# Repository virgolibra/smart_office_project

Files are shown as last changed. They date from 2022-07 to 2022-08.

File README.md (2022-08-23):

# smart_office_project

This is the repo for MSc CE dissertation.

### Introduce

The project introduces a method to build a seat occupancy system with a smart IoT office system. It contains three subsystems, which are smart chair system, smart desk occupancy system and smart desktop clock system, to provide desk occupancy monitoring, chair occupancy monitoring, desk check-in and out, and office indoor environmental parameter measurement. A Flutter App is designed for user interaction and data visualisation. 3D print PLA enclosure are used for sensor boxes. The system can be deployed in the office or study space.

------

### Hardware Requirements

+ Seat pressure sensors and Zigbee binary sensors.
+ Infrared motion sensor with ESP8266 NodeMCU module.
+ Integrated desktop clock with Arduino Nano 33 IoT.

##### Components List

+ Hub and Gateway

  + Raspberry Pi
  + ConBee II ZigBee Gateway

+ Chair sensor

  + Aqara water leak sensor

  + Seat pressure sensor

  + CR2032 Lithium Battery

+ Smart Desktop Clock

  + Arduino Nano 33 IoT
  + NeoPixel Stick
  + RC522 RFID module
  + BMP180 Sensor
  + TM1637 4-digits Display

+ Smart Desk Occupancy System

  + Lithium polymer ion battery
  + ESP8266 NodeMCU
  + HC-SR312 PIR motion sensor

+ Circuit board components

  + Stripboards
  + Solid wires
  + Connectors

+ Enclosures

  + 3D printed boxes and connectors
  + Cushion 

----------

### Software requirements

#### Home Assistant Installation

**Prerequisites:** 

1. Raspberry Pi 4
2. Power supply
3. SD card reader
4. Micro SD card

**Boot media:**

1. Attach SD card to computer as the boot media.
2. Download flasher software. ([Balena Etcher](https://www.balena.io/etcher/))
3. Flash from URL ```https://github.com/home-assistant/operating-system/releases/download/8.4/haos_rpi4-64-8.4.img.xz``` for Raspberry Pi 4 64-bit.
4. Download image, select SD card and flash.

**Setup Wi-Fi:**

1. Place the flashed SD card to a Windows PC.

2. Open it with file explorer.

3. Create a new folder named "CONFIG".

4. Open the folder and create another folder named "network"

5. Open the "network" folder create a plain text file named "my-network".

6. Edit it as follows. The [online UUID generator](https://www.uuidgenerator.net/version1)

   ```properties
   [connection]
   id=my-network
   uuid=72111c67-4a5d-4d5c-925e-f8ee26efb3c3
   type=802-11-wireless
   
   [802-11-wireless]
   mode=infrastructure
   ssid=MY_SSID
   # Uncomment below if your SSID is not broadcasted
   #hidden=true
   
   [802-11-wireless-security]
   auth-alg=open
   key-mgmt=wpa-psk
   psk=MY_WLAN_SECRET_KEY
   
   [ipv4]
   method=auto
   
   [ipv6]
   addr-gen-mode=stable-privacy
   method=auto
   ```

7. Save the changes, remove the SD card and plug into Raspberry Pi.
8. Boot Raspberry Pi, the specified network should be connected.

**Config Home Assistant**

1. After network connection, Home Assistant can be accessed in the browser of the Desktop system on `homeassistant.local:8123`, or `homeassistant:8123`, or `http://[IPAddress]:8123`in a few minutes.
2. Follow the instructions in [Home Assistant official guideline](https://www.home-assistant.io/getting-started/onboarding/).

#### Flutter Mobile App

**Prerequisites:** 

1. Any Operating System (Linux, Windows, MacOS etc.)
2. Any IDE with Flutter SDK installed (VSCode, Android Studio, XCode, etc.)
3. Basic knowledge and practice of Flutter and Dart.
4. Setup Firebase App based on [Firebase official guideline](https://firebase.google.com/docs/guides).

**Dependencies:**

```yaml
  cupertino_icons: ^1.0.2
  cloud_firestore: ^3.1.14
  firebase_auth: ^3.3.17
  firebase_core: ^1.12.0
  firebase_storage: ^10.2.16
  provider: ^6.0.2
  google_fonts: ^2.3.2
  bottom_bar: ^1.3.0+1
  geolocator: ^8.2.0
  weather: ^2.0.1
  mqtt_client: ^9.6.2
  camera: ^0.9.4+21
```

----

### Data Visualisation

#### Grafana with InfluxDB in Home Assistant

Home Assistant 

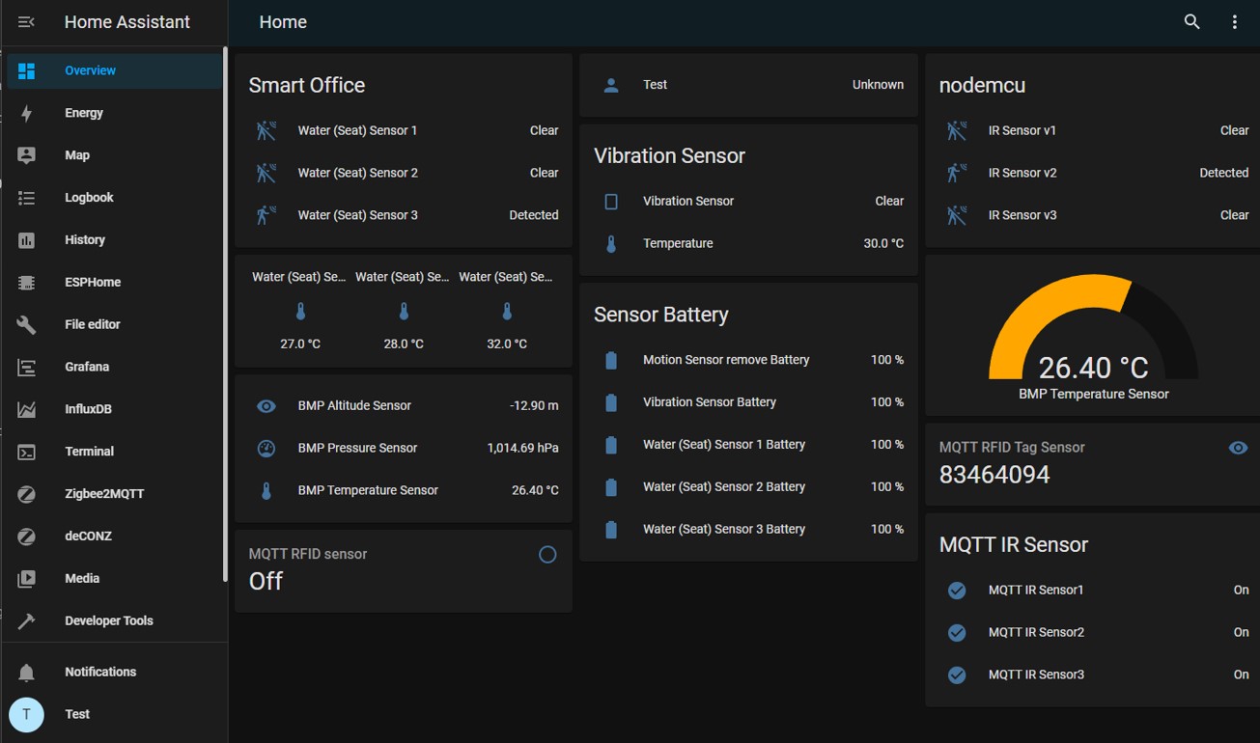
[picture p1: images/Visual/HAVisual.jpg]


Grafana

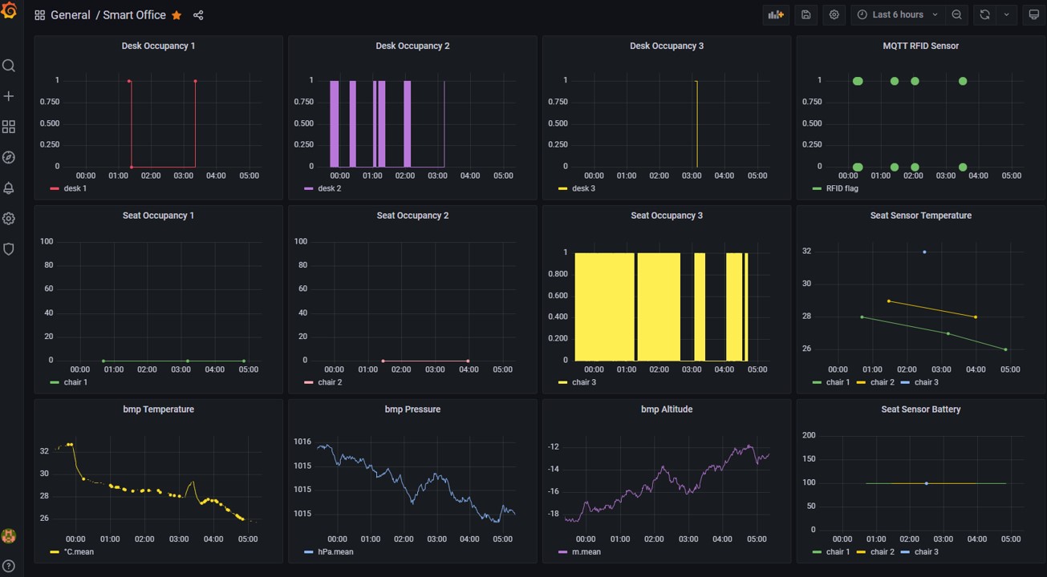
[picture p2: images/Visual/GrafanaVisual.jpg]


App

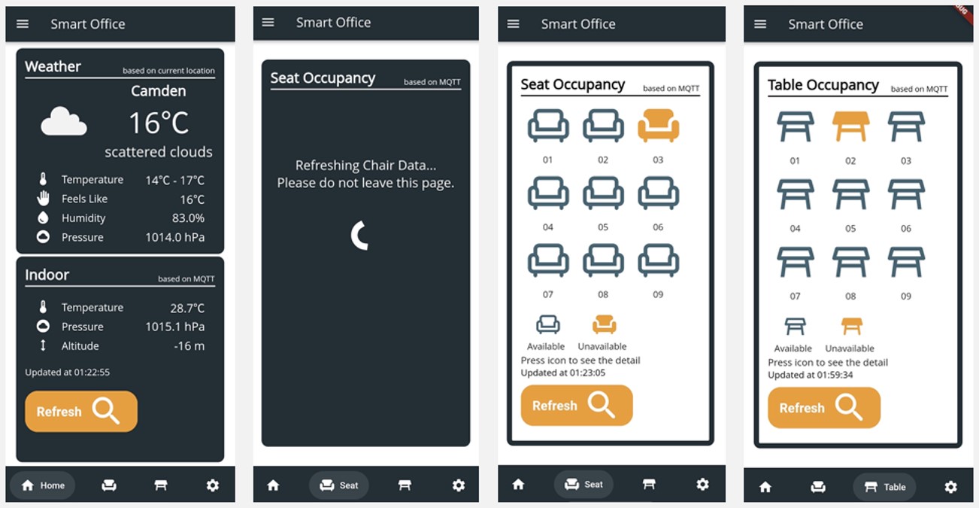
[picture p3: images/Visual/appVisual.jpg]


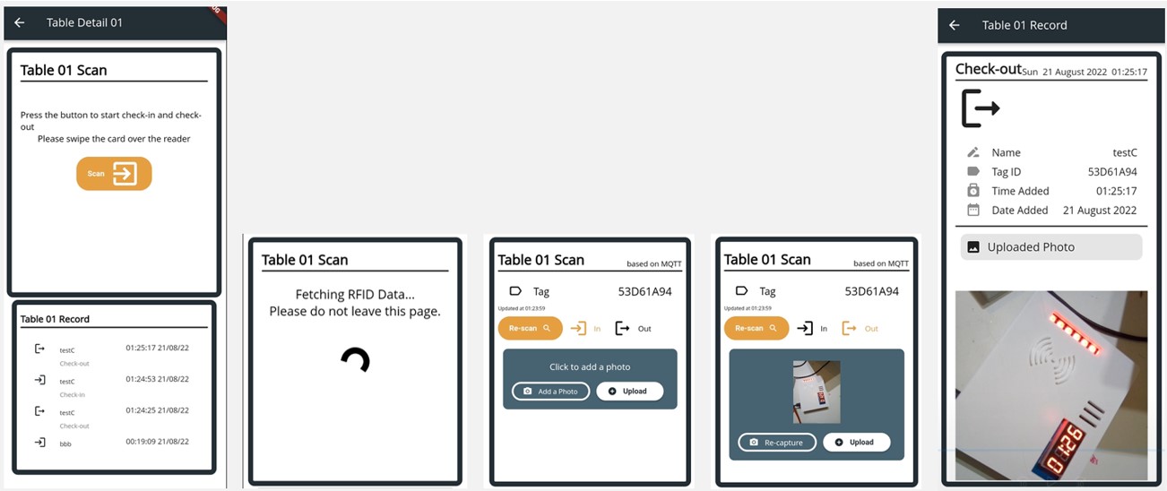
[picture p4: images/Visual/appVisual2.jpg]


----

### Application Demo YouTube Link

https://youtube.com/shorts/BBJ_iGN9C2Y?feature=share

-----

## Contact Details

If you have any questions, please feel free to contact me: [minghao.zhang.21@ucl.ac.uk](https://github.com/virgolibra/casa0015-mobile-assessment/blob/master/minghao.zhang.21@ucl.ac.uk)

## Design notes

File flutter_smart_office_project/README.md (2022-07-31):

# flutter_smart_office_project

A new Flutter application.

## Getting Started

This project is a starting point for a Flutter application.

A few resources to get you started if this is your first Flutter project:

- [Lab: Write your first Flutter app](https://flutter.dev/docs/get-started/codelab)
- [Cookbook: Useful Flutter samples](https://flutter.dev/docs/cookbook)

For help getting started with Flutter, view our
[online documentation](https://flutter.dev/docs), which offers tutorials,
samples, guidance on mobile development, and a full API reference.

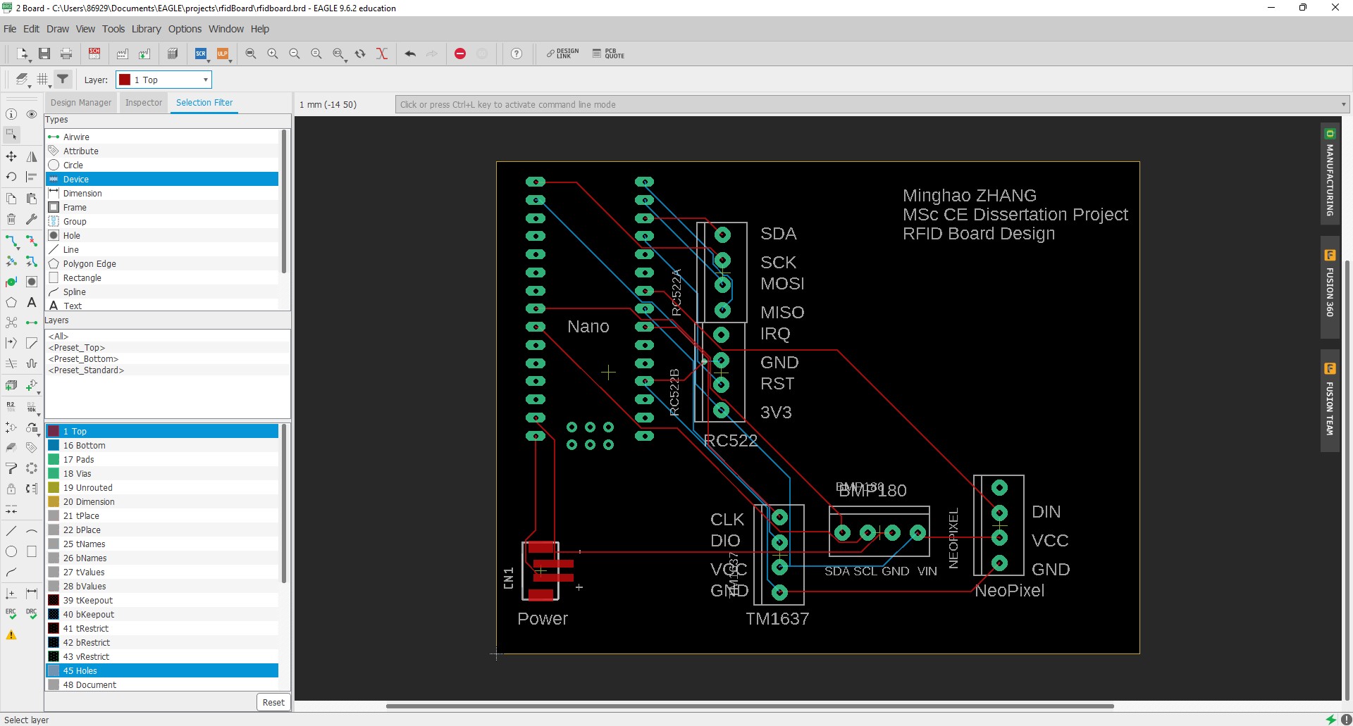
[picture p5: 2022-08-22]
images/PCBdesign/rfidBoardAllLayer.jpg

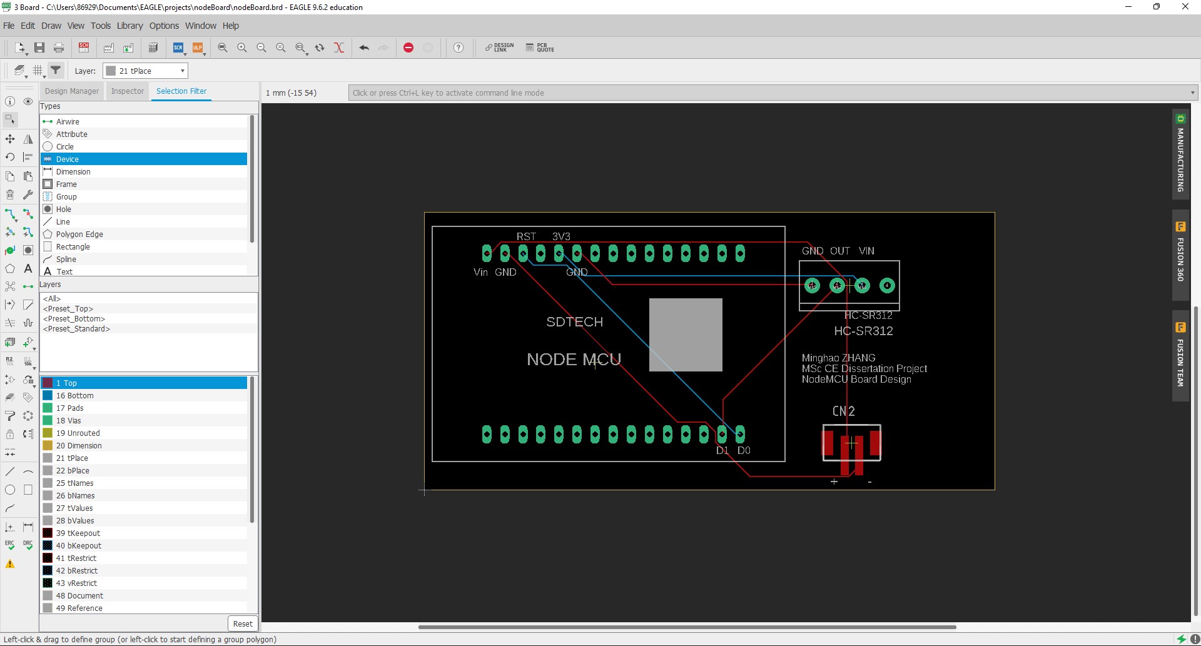
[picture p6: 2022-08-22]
images/PCBdesign/nodeBoardAllLayer.jpg

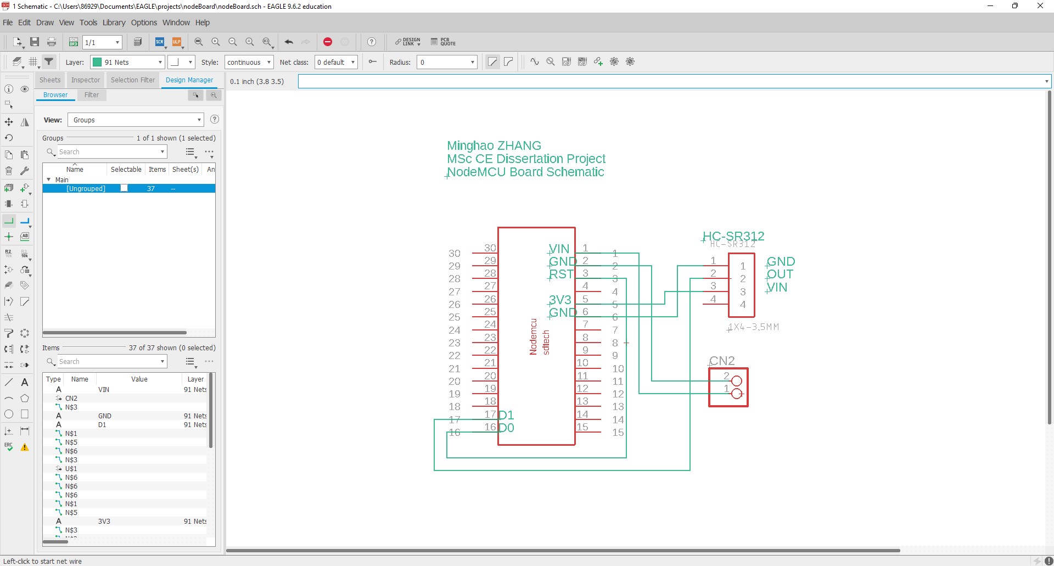
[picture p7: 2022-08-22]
images/PCBdesign/nodeBoardSchematic.jpg

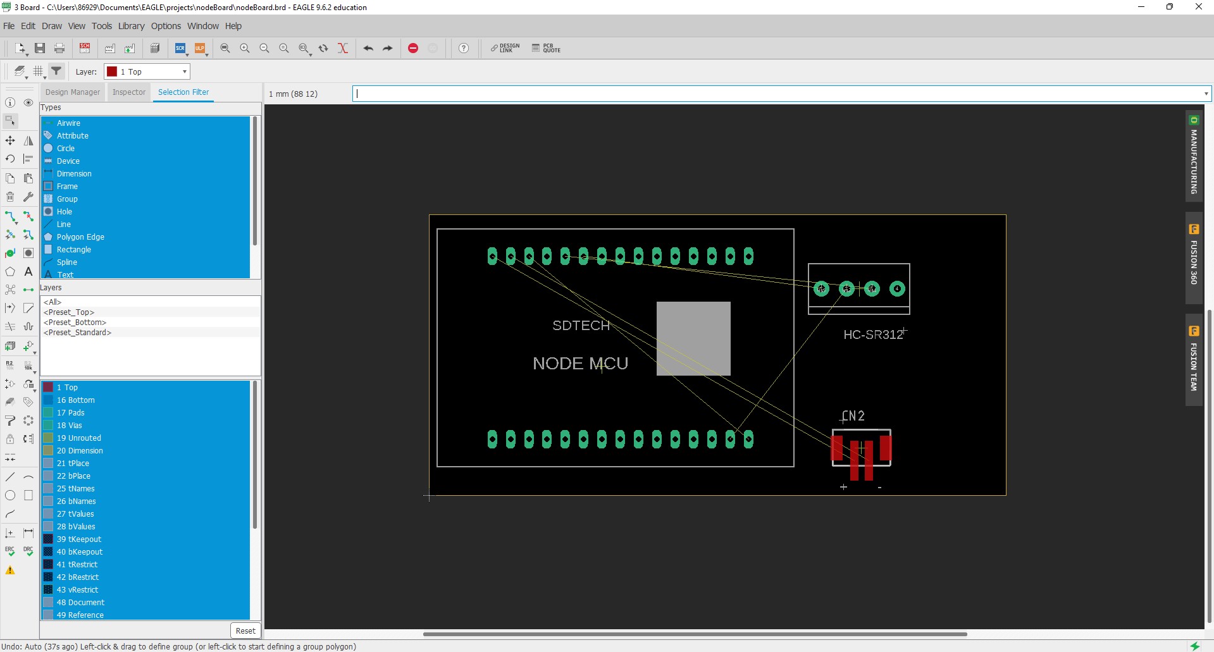
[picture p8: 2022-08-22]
images/PCBdesign/nodeBoardAirWire.jpg

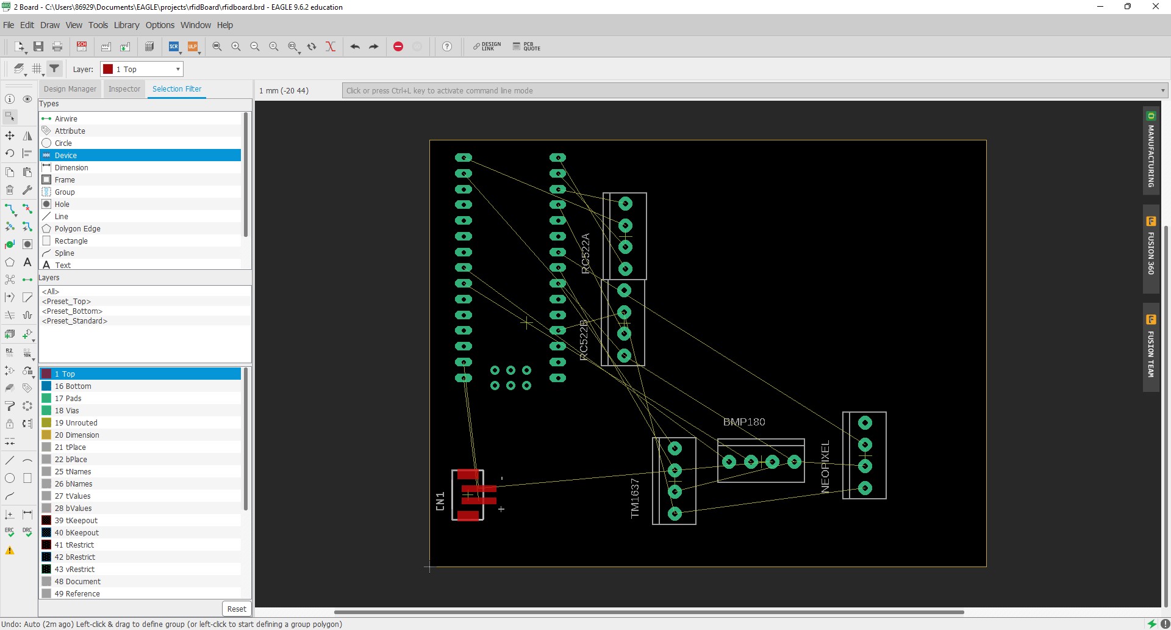
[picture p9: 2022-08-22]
images/PCBdesign/rfidBoardAirWire.jpg

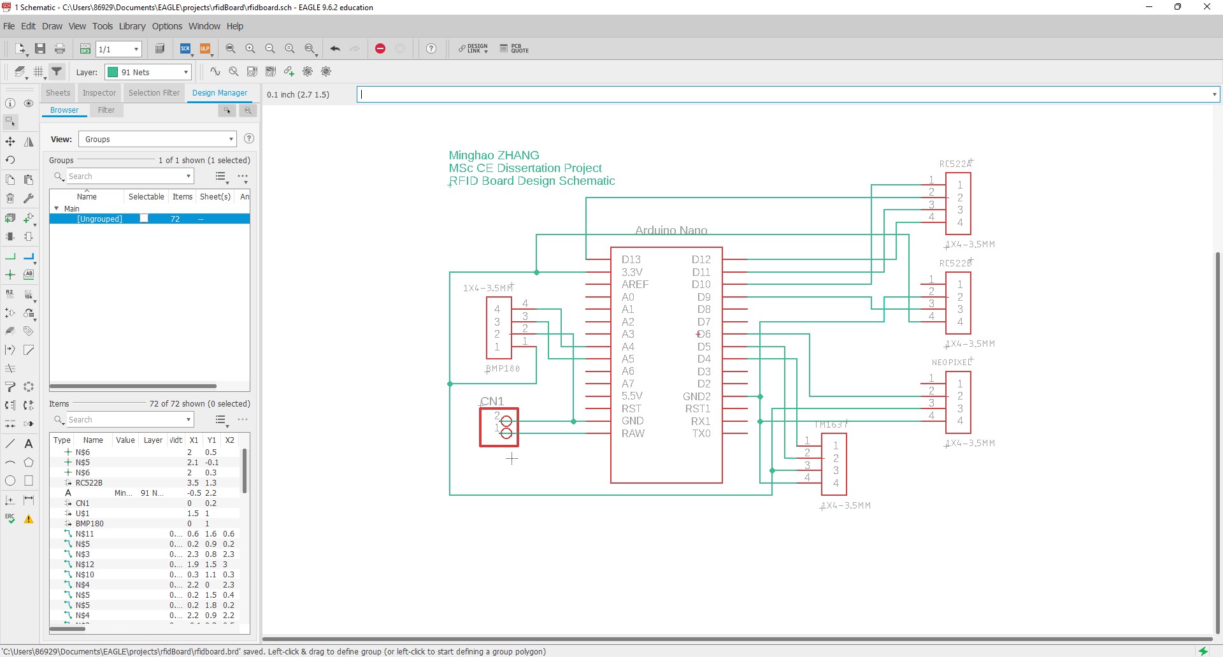
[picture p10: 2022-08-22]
images/PCBdesign/rfidBoardSchematic.jpg

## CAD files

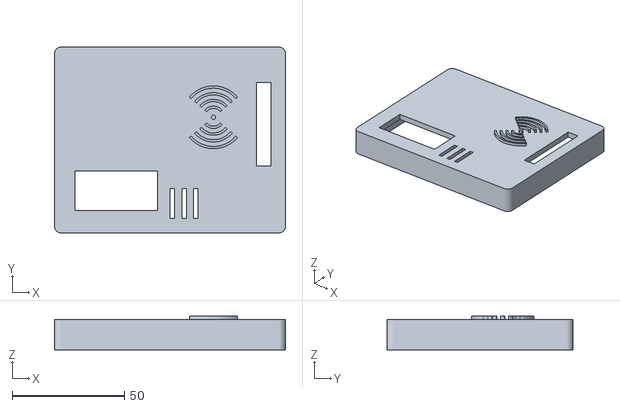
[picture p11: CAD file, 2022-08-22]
fusion3DModel/RFIDcoverAugustV1.stl
103.0 x 83.0 x 15.0

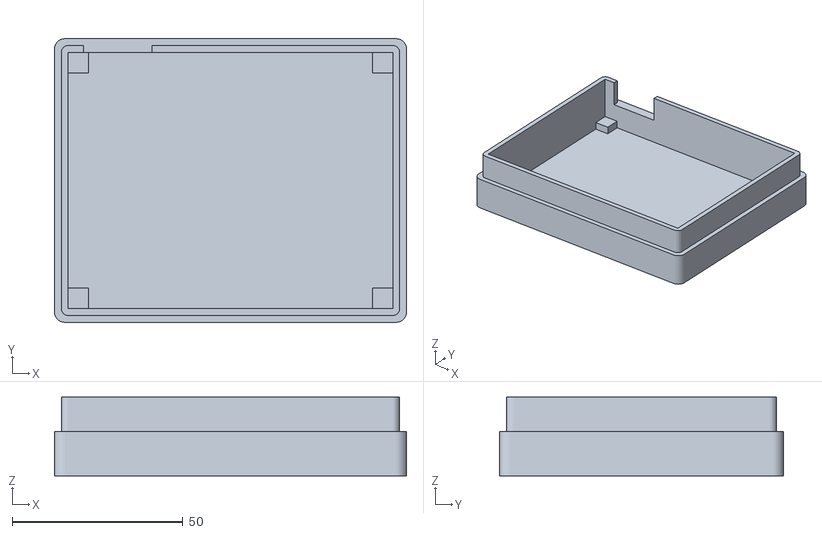
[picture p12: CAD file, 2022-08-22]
fusion3DModel/RFIDbaseAugustV1.stl
103.0 x 83.0 x 23.0

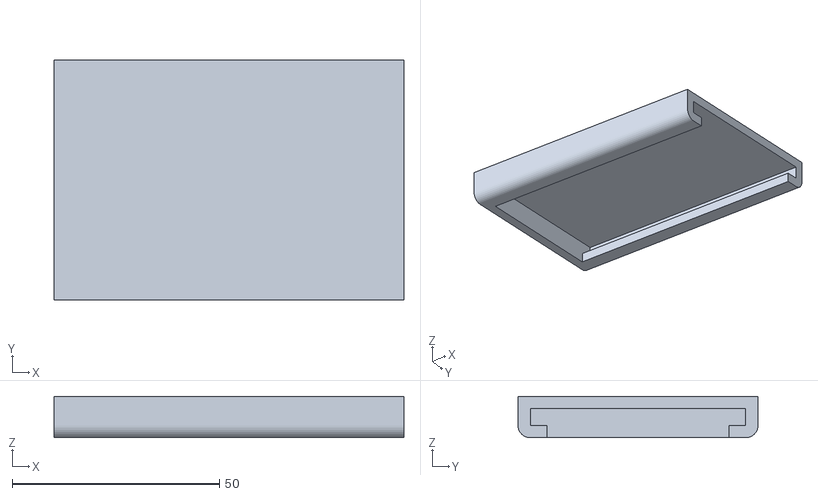
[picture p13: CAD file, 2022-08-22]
fusion3DModel/IRboxHolderAugustV1.stl
84.5 x 58.0 x 10.0

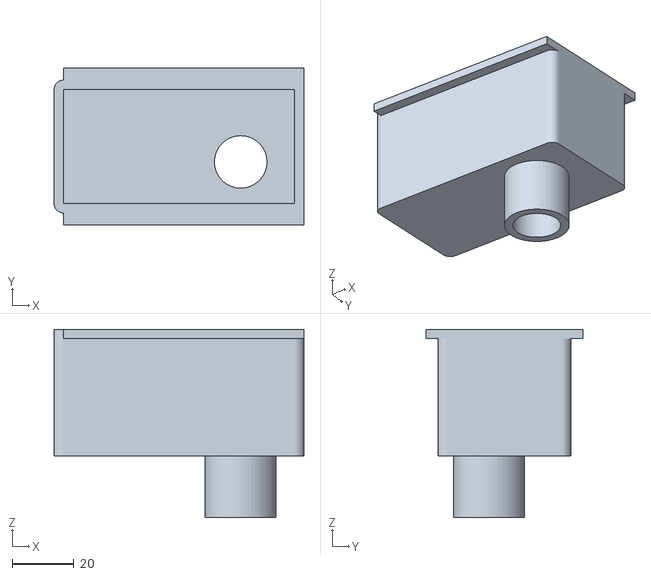
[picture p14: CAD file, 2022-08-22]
fusion3DModel/IRboxBaseAugustV1.stl
81.0 x 51.0 x 61.0

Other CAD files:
fusion3DModel/IRboxAugust v4.f3d
fusion3DModel/RFIDBox v2.f3d

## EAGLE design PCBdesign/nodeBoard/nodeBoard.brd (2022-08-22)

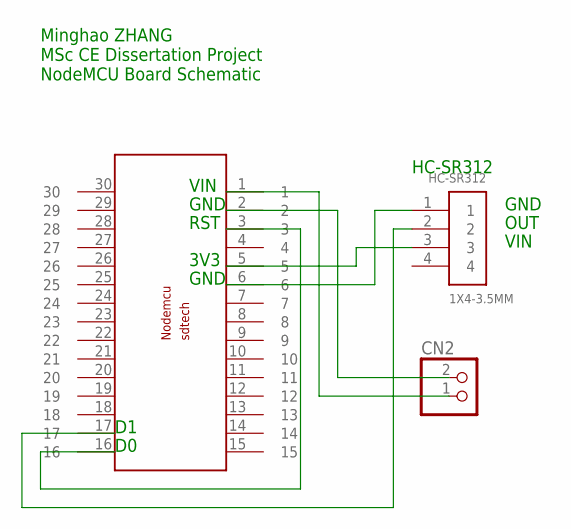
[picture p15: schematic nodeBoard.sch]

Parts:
CN2: JST_2PIN-SMT; JST-PH-2-SMT
HC-SR312: 1X4-3.5MM; 1X04-3.5MM
U$1: NODEMCUESP8266

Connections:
unnamed: CN2.1 (2), U$1.1
unnamed: CN2.2 (1), U$1.2
unnamed: HC-SR312.2, U$1.17
unnamed: HC-SR312.3, U$1.5
unnamed: HC-SR312.1, U$1.6
unnamed: U$1.3, U$1.16

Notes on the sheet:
Minghao ZHANG MSc CE Dissertation Project NodeMCU Board Schematic
HC-SR312
OUT
GND
VIN
RST
3V3

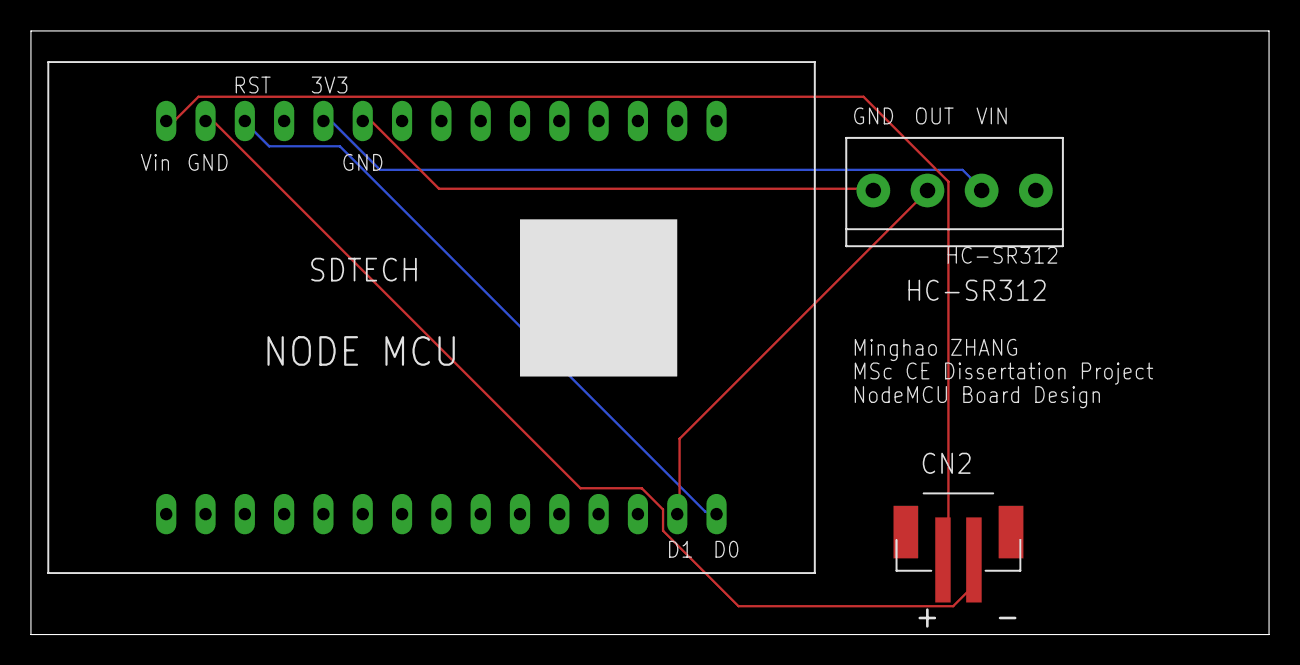
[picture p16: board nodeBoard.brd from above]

Board: 2 copper layers, 80.0 x 39.0 mm, 3 parts (0 on the bottom side), 6 nets.

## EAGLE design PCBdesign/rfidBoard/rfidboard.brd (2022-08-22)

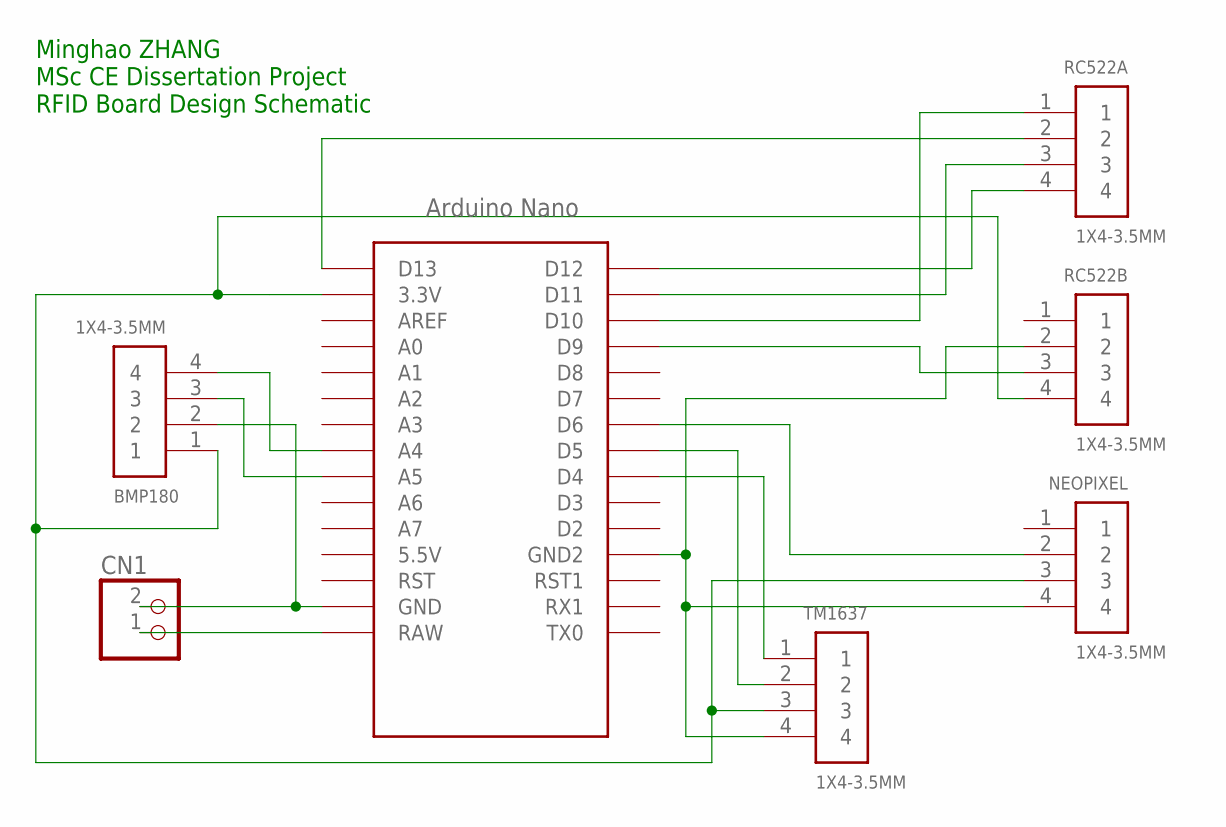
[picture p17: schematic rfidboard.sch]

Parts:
BMP180: 1X4-3.5MM; 1X04-3.5MM
CN1: JST_2PIN-SMT; JST-PH-2-SMT
NEOPIXEL: 1X4-3.5MM; 1X04-3.5MM
RC522A, RC522B: 1X4-3.5MM; 1X04-3.5MM
TM1637: 1X4-3.5MM; 1X04-3.5MM
U$1: NANO

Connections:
unnamed: CN1.1 (2), U$1.RAW
unnamed: BMP180.2, CN1.2 (1), U$1.GND
unnamed: TM1637.1, U$1.D4
unnamed: TM1637.2, U$1.D5
unnamed: BMP180.1, NEOPIXEL.3, RC522B.4, TM1637.3, U$1.3.3V
unnamed: NEOPIXEL.4, RC522B.2, TM1637.4, U$1.GND1 (GND2)
unnamed: NEOPIXEL.2, U$1.D6
unnamed: RC522A.1, U$1.D10
unnamed: BMP180.4, U$1.A4
unnamed: BMP180.3, U$1.A5
unnamed: RC522A.2, U$1.D13
unnamed: RC522A.3, U$1.D11
unnamed: RC522A.4, U$1.D12
unnamed: RC522B.3, U$1.D9

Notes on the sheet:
Minghao ZHANG MSc CE Dissertation Project RFID Board Design Schematic

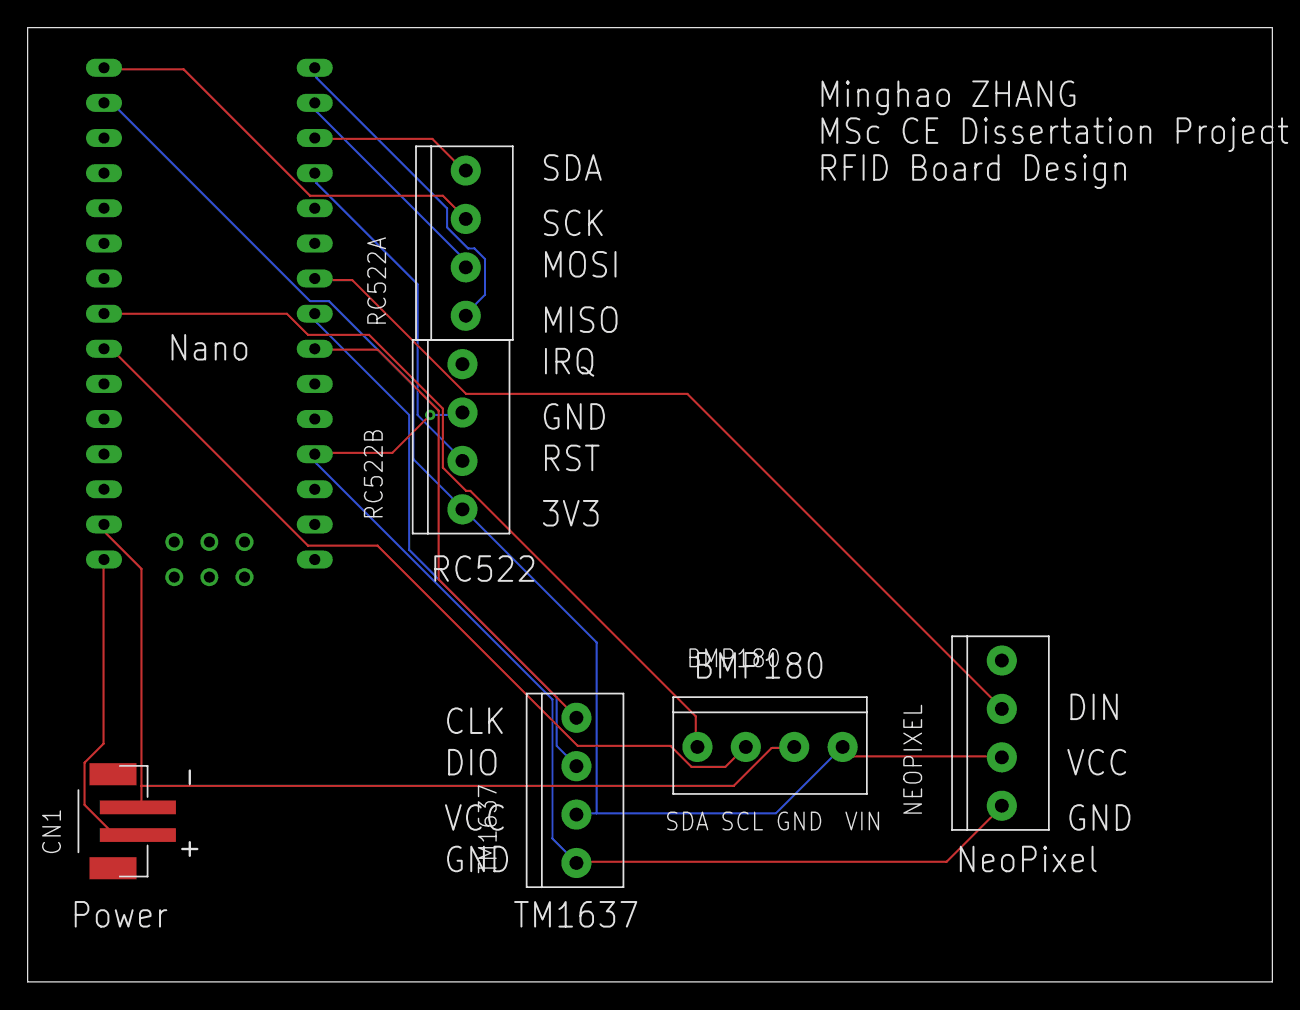
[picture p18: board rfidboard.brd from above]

Board: 2 copper layers, 90.0 x 69.0 mm, 7 parts (0 on the bottom side), 14 nets.

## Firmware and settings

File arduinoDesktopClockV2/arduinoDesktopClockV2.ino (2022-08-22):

#include <SPI.h>
#include <MFRC522.h>
#include <Adafruit_NeoPixel.h>
#include <TM1637.h>
#include <Wire.h>
#include <Adafruit_BMP085.h>
#include <ArduinoMqttClient.h>  // MQTT

#include <WiFiNINA.h>
#include <WiFiUdp.h>
#include <RTCZero.h>
#include "arduino_secrets.h"


#define RST_PIN 9
#define SS_PIN 10
#define pixelPin 6
#define TM_CLK 4
#define TM_DIO 5

#define NUMPIXELS 8
#define pixelBrightness 5
#define seaLevelPressure_hPa 1013.25  // Pressure at sea level

// ------------------ Wi-Fi and MQTT connection ----------------------------------------------------
char ssid[] = SECRET_SSID;        // your network SSID
char pass[] = SECRET_PASS;    // your network password
const char* mqttuser = SECRET_MQTTUSER;
const char* mqttpass = SECRET_MQTTPASS;

int keyIndex = 0;                 // your network key Index number (needed only for WEP)
int status = WL_IDLE_STATUS;      //connection status

WiFiClient wifiClient;
MqttClient mqttClient(wifiClient);


const char broker[] = "mqtt.cetools.org";
int        port     = 1884;
const char topic1_temperature[]  = "student/CASA0022/ucfnmz0/nano33/temperature";
const char topic2_tagID[]  = "student/CASA0022/ucfnmz0/nano33/tagID";
const char topic3_pressure[]  = "student/CASA0022/ucfnmz0/nano33/pressure";
const char topic4_altitude[]  = "student/CASA0022/ucfnmz0/nano33/altitude";
const char topic5_tagFlag[]  = "student/CASA0022/ucfnmz0/nano33/tagFlag";
//const char topic5_ppm[]  = "student/CASA0016/project/ucfnmz0/ppm";
//const char topic6_sound[]  = "student/CASA0016/project/ucfnmz0/soundStatus";
//const char topic7_uv[]  = "student/CASA0016/project/ucfnmz0/uvValue";

// -------------------------------------------

const int GMT = 1;
RTCZero rtc_wifi;

// Variable to represent epoch
unsigned long epoch;

// Variable for number of tries to NTP service
int numberOfTries = 0, maxTries = 5;

bool timeFlag = false;


byte set_year = 0; // can only be 2-digit year
byte set_month = 0;
byte set_date = 0;
byte set_hour = 0;
byte set_minute = 0;
byte set_second = 0;
void initRealTime() {
  set_year = rtc_wifi.getYear(); // can only be 2-digit year
  set_month = rtc_wifi.getMonth();
  set_date = rtc_wifi.getDay();
  set_hour = rtc_wifi.getHours();
  set_minute = rtc_wifi.getMinutes();
  set_second = rtc_wifi.getSeconds();
}

byte readCard[4];
//String MasterTag = "20C3935E";  // REPLACE this Tag ID with your Tag ID!!!
String MasterTag = "83464094";  // REPLACE this Tag ID with your Tag ID!!!
String tagID = "";

// Create instances
MFRC522 mfrc522(SS_PIN, RST_PIN);
Adafruit_NeoPixel pixels(NUMPIXELS, pixelPin);
TM1637 tm(TM_CLK, TM_DIO);
Adafruit_BMP085 bmp;

float bmpTemperature = 0;
float bmpPressure = 0; // pressure and altitude (BMP180)
float bmpAltitude = 0;
unsigned int tagFlag = 0;



void setup()
{
  // Initiating
  Serial.begin(9600);   // Initialize serial communications with the PC
//  while (!Serial);

  // ------------- WIFI & MQTT init --------------------


  // attempt to connect to Wifi network:
  Serial.print("Attempting to connect to SSID: ");
  Serial.println(ssid);

  setupPixelDisplay(2);
  while (WiFi.begin(ssid, pass) != WL_CONNECTED) {
    // failed, retry
    Serial.print(".");
    delay(5000);
  }

  Serial.println("You're connected to the network");
  Serial.println();

  setupPixelDisplay(3);
  delay(1000);

  Serial.print("Attempting to connect to the MQTT broker: ");
  Serial.println(broker);

  setupPixelDisplay(4);
  mqttClient.setUsernamePassword(mqttuser, mqttpass);
  if (!mqttClient.connect(broker, port)) {
    Serial.print("MQTT connection failed! Error code = ");
    Serial.println(mqttClient.connectError());

    while (1);
  }

  Serial.println("You're connected to the MQTT broker!");
  Serial.println();

  setupPixelDisplay(5);
  delay(1000);

  //----------------------------------


  SPI.begin(); // SPI bus
  mfrc522.PCD_Init(); // MFRC522
  pixels.begin();
  setScaningPixelDisplay();
  delay(200);


  Serial.println("Scan Your Card>>");
  displayNumber(0000);

  // BMP180 init and check if BMP180 exist
  if (!bmp.begin()) {
    Serial.println("Cannot find BMP180 Module");
    while (1) {}
  }


  // ------------- Time display --------------------
  tm.init();
  tm.set(2);  //set brightness; 0-7

  delay(1000);
  // Start Real Time Clock
  rtc_wifi.begin();


  do {
    epoch = WiFi.getTime();
    Serial.print(WiFi.getTime());
    numberOfTries++;
    Serial.print("tryGetTime");
    delay(200);
  }

  while ((epoch == 0) && (numberOfTries < maxTries));

  if (numberOfTries == maxTries) {
    Serial.print("NTP unreachable!!");
    while (1);
  }

  else {
    Serial.print("Epoch received: ");
    Serial.println(epoch);
    rtc_wifi.setEpoch(epoch + GMT * 60 * 60);
    Serial.println();
  }

  initRealTime();
  Serial.println("Initializing real time done.");
  Serial.println("Online date & time: " + String(set_year) + "-" + String(set_month) + "-" + String(set_date) + " " + String(set_hour) + ":" + String(set_minute) + ":" + String(set_second));



  // -------------- init sensor data update --------
  displayTime();
  getBmpData();
  sendMQTT();

  Serial.println();

  delay(1000);
}

void loop()
{


  mqttClient.poll();


  displayTime();
  getBmpData();
  getID();
  sendMQTT();

  if ((rtc_wifi.getSeconds() > 10) && (timeFlag == false) ) {
    if (getEpochFromWifi()) {
      Serial.println("Time calibration failed");
    } else {
      Serial.println("Time calibrated");
      timeDonePixelDisplay();

    }
    timeFlag = true;
    Serial.println("timeFlag == true");
  }

  if ((rtc_wifi.getSeconds() > 0) && (rtc_wifi.getSeconds() < 10) && (timeFlag == true)) {
    timeFlag = false;

    Serial.println("timeFlag == false");
  }
  delay(2000);


  //
  //  //Wait until new tag is available
  //  while (getID())
  //  {
  //
  //
  //    if (tagID == MasterTag)
  //    {
  //      setGrantedPixelDisplay();
  //      Serial.println(" Access Granted!");
  //      // You can write any code here like opening doors, switching on a relay, lighting up an LED, or anything else you can think of.
  //
  //
  //
  //    }
  //    else
  //    {
  //      setDeniedPixelDisplay();
  //
  //      Serial.println(" Access Denied!");
  //    }
  //
  //    Serial.print(" ID : ");
  //    Serial.println(tagID);
  //
  //    delay(2000);
  //
  //    setScaningPixelDisplay();
  //
  //    Serial.println(" Access Control ");
  //    Serial.println("Scan Your Card>>");
  //  }
}

//Read new tag if available
boolean getID()
{
  tagFlag = 0;
  // Getting ready for Reading PICCs
  if ( ! mfrc522.PICC_IsNewCardPresent()) { //If a new PICC placed to RFID reader continue
    return false;
  }
  if ( ! mfrc522.PICC_ReadCardSerial()) { //Since a PICC placed get Serial and continue
    return false;
  }
  tagID = "";
  for ( uint8_t i = 0; i < 4; i++) { // The MIFARE PICCs that we use have 4 byte UID
    //readCard[i] = mfrc522.uid.uidByte[i];
    tagID.concat(String(mfrc522.uid.uidByte[i], HEX)); // Adds the 4 bytes in a single String variable
  }
  tagID.toUpperCase();
  mfrc522.PICC_HaltA(); // Stop reading
  cardReadPixelDisplay();
  tagFlag = 1;
  return true;
}

void setDeniedPixelDisplay() {
  pixels.clear();
  for (int i = 0; i < NUMPIXELS; i++) {
    pixels.setPixelColor(i, 204, 102, 0); // orange
    pixels.setBrightness(pixelBrightness);
  }
  pixels.show();
}

void setGrantedPixelDisplay() {
  pixels.clear();
  for (int i = 0; i < NUMPIXELS; i++) {
    //    pixels.setPixelColor(i, 150, 0, 0); //red
    pixels.setPixelColor(i, 0, 155, 0); //green
    pixels.setBrightness(pixelBrightness);
  }

  pixels.show();
}

void setScaningPixelDisplay() {
  pixels.clear();
  for (int i = 0; i < NUMPIXELS; i++) {
    //    pixels.setPixelColor(i, 150, 0, 0); //red
    pixels.setPixelColor(i, 0, 0, 155); //blue
    pixels.setBrightness(pixelBrightness);
  }

  pixels.show();
}

void setupPixelDisplay(int numberOfPixelOn) {
  pixels.clear();
  for (int i = 0; i < numberOfPixelOn; i++) {
    pixels.setPixelColor(i, 150, 0, 0); // red
    pixels.setBrightness(pixelBrightness);
  }
  pixels.show();
}

void mqttUploadPixelDisplay() {
  //  for (int i = 0; i < NUMPIXELS; i++) {
  //    pixels.clear();
  //    pixels.setPixelColor(i, 0, 102, 204); // blue
  //    pixels.setBrightness(pixelBrightness);
  //    pixels.show();
  //    delay(50);
  //  }
  //
  //  pixels.clear();
  //  pixels.show();
  //  delay(100);
  //
  //  for (int i = 0; i < NUMPIXELS; i++) {
  //    pixels.setPixelColor(i, 0, 102, 204); // blue
  //    pixels.setBrightness(pixelBrightness);
  //  }
  //  pixels.show();

  pixels.clear();
  for (int i = 0; i < 8; i++) {
    pixels.setPixelColor(i, 150, 0, 0); // red
    pixels.setBrightness(pixelBrightness);
  }
  pixels.show();

}

void timeDonePixelDisplay() {
  for (int i = 0; i < NUMPIXELS; i++) {
    pixels.clear();
    pixels.setPixelColor(i, 153, 102, 204); // purple
    pixels.setBrightness(pixelBrightness);
    pixels.show();
    delay(50);
  }

  pixels.clear();
  pixels.show();
  delay(100);

  for (int i = 0; i < NUMPIXELS; i++) {
    pixels.setPixelColor(i, 153, 102, 204); // purple
    pixels.setBrightness(pixelBrightness);
  }
  pixels.show();



}


void cardReadPixelDisplay() {
  for (int i = 0; i < NUMPIXELS; i++) {
    pixels.clear();
    pixels.setPixelColor(i, 0, 140, 20); // green
    pixels.setBrightness(pixelBrightness);
    pixels.show();
    delay(50);
  }

  pixels.clear();
  pixels.show();
  delay(100);

  for (int i = 0; i < NUMPIXELS; i++) {
    pixels.setPixelColor(i, 0, 140, 20); // blue
    pixels.setBrightness(pixelBrightness);
  }
  pixels.show();

  delay(1000);


}

void displayNumber(int num) {
  tm.display(3, num % 10);
  tm.display(2, num / 10 % 10);
  tm.display(1, num / 100 % 10);
  tm.display(0, num / 1000 % 10);
}


void displayTime() {

  // display hour
  int numHour = rtc_wifi.getHours();
  tm.display(1, numHour % 10);
  tm.display(0, numHour / 10 % 10);

  // display minute
  int numMinute = rtc_wifi.getMinutes();
  tm.display(3, numMinute % 10);
  tm.display(2, numMinute / 10 % 10);

  tm.point(1);

}

void getBmpData() {
  bmpTemperature = bmp.readTemperature();
  bmpPressure = bmp.readSealevelPressure() * 0.01;
  bmpAltitude = bmp.readAltitude(seaLevelPressure_hPa * 100);

  Serial.print(">>> BMP Update |");
  Serial.print("Temperature: ");
  Serial.print(bmpTemperature);
  Serial.print(" *C");
  Serial.print(" | Pressure: ");
  Serial.print(bmpPressure);
  Serial.print(" hPa");
  Serial.print(" | Real altitude: ");
  Serial.print(bmpAltitude);
  Serial.println(" meters");

}
// ------------------------------------------------------------------------------------
//                                    send MQTT
// ------------------------------------------------------------------------------------
void sendMQTT() {



  // call poll() regularly to allow the library to send MQTT keep alive which
  // avoids being disconnected by the broker
  mqttClient.poll();

  if (mqttClient.connected()) {
    // send message, the Print interface can be used to set the message contents
    mqttClient.beginMessage(topic1_temperature);
    mqttClient.print(bmpTemperature);
    mqttClient.endMessage();

    mqttClient.beginMessage(topic2_tagID);
    mqttClient.print(tagID);
    mqttClient.endMessage();

    mqttClient.beginMessage(topic3_pressure);
    mqttClient.print(bmpPressure);
    mqttClient.endMessage();

    mqttClient.beginMessage(topic4_altitude);
    mqttClient.print(bmpAltitude);
    mqttClient.endMessage();

    mqttClient.beginMessage(topic5_tagFlag);
    mqttClient.print(tagFlag);
    mqttClient.endMessage();

    //    mqttClient.beginMessage(topic5_ppm);
    //    mqttClient.print(mqPPM);
    //    mqttClient.endMessage();
    //
    //    mqttClient.beginMessage(topic6_sound);
    //    mqttClient.print(soundDetectorStatus);
    //    mqttClient.endMessage();
    //
    //    mqttClient.beginMessage(topic7_uv);
    //    mqttClient.print(uvValue);
    //    mqttClient.endMessage();

    Serial.println("Sending messages to MQTT done!");
    Serial.println();

    mqttUploadPixelDisplay();
  }

  else { // if the client has been disconnected,
    Serial.println("Client disconnected, attempting reconnection");
    Serial.println();


    if (!attemptReconnect()) { // try reconnecting
      Serial.print("Client reconnected!");
      Serial.println();

    }

  }

}


int attemptReconnect() {
  if (!mqttClient.connect(broker, port)) {
    Serial.print("MQTT connection failed! Error code = ");
    Serial.println(mqttClient.connectError());

  }
  return mqttClient.connectError(); // return status
}


int getEpochFromWifi() {
  // Get epoch
  do {
    epoch = WiFi.getTime();
    Serial.print(WiFi.getTime());
    numberOfTries++;
    Serial.print("tryGetTime");
    delay(200);
  }

  while ((epoch == 0) && (numberOfTries < maxTries));

  if (numberOfTries == maxTries) {
    Serial.print("NTP unreachable!!");
    return 1;
  }

  else {
    Serial.print("Epoch received: ");
    Serial.println(epoch);
    rtc_wifi.setEpoch(epoch + GMT * 60 * 60);
    Serial.println();
  }

  initRealTime();
  Serial.println("Initializing real time done.");
  Serial.println("Online date & time: " + String(set_year) + "-" + String(set_month) + "-" + String(set_date) + " " + String(set_hour) + ":" + String(set_minute) + ":" + String(set_second));
  return 0;



}

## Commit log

2022-08-22 update materials
    [IRboxBaseAugustV1.stl, IRboxHolderAugustV1.stl, RFIDbaseAugustV1.stl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]
2022-08-22 update 3d models
    [IRboxAugust v4.f3d, RFIDBox v2.f3d]
